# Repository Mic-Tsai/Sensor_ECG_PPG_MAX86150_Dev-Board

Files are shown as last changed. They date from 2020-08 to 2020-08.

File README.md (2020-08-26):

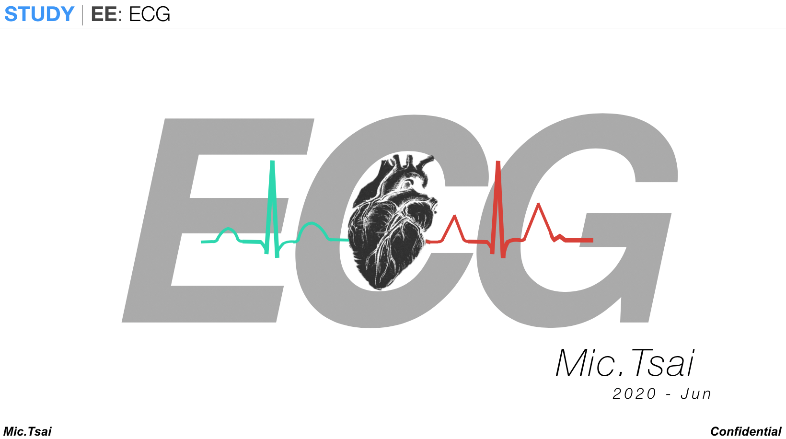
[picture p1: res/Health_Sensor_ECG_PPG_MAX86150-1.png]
*Sensor_MAX86150*

## Sensor_ECG_PPG_MAX86150 | Dev-Board



Arduino based sensor learning project. The feature combines ECG/PPG data with heart rate calculation, plotting the ECG/PPG curve which used Processing on your computer.

 - Bias Cancellation | Store raw data in time, when new data coming that bias level will calculate as hysteresis filter.

 - Heart Rate Detect | Setting upper/lower threshold once your ECG/PPG value cross u/l threshold, check windows will output the BPM results (Both PPG/ECG).

##

### Wireless Support ###

This board also support WiFi transmission via ESPNOW (ESP8266 Broadcast), and need power by battery. And you need 2x esp8266 board.

1) Read receiver esp8266's mac address.
2) Fill it into the transmitter sketch. "ECG_PPG_MAX86150_V5_WiFi_TX"

**A Known Issue**

Sampling rate from MAX86150 set as 200sps, but ESP8266's multiplex with ESP-NOW and sensor hub reading task, it will low down the output sample rate to ~150sps. So, when you measuring your ECG/PPG in real-time plot, it may show the missing R-R interval. (R-peak missing!) Don't worry it just the lower sample rate caused.

```
Arduino tool kit, and require the following material:
- MCU: ESP8266 
- Display: SD1306_128x64_OLED
- Sensor: MAX86150
```
##

For coding example, you need the following library:

* [Adafruit_SSD1306](https://github.com/adafruit/Adafruit_SSD1306)
* [protocentral_max86150_ecg_ppg](https://github.com/Protocentral/protocentral_max86150_ecg_ppg)

## 

Any question or need technical support:

* Contact me via mail (xbcke12345@gmail.com)
* If this project helping. Please generously support =)

   

## 
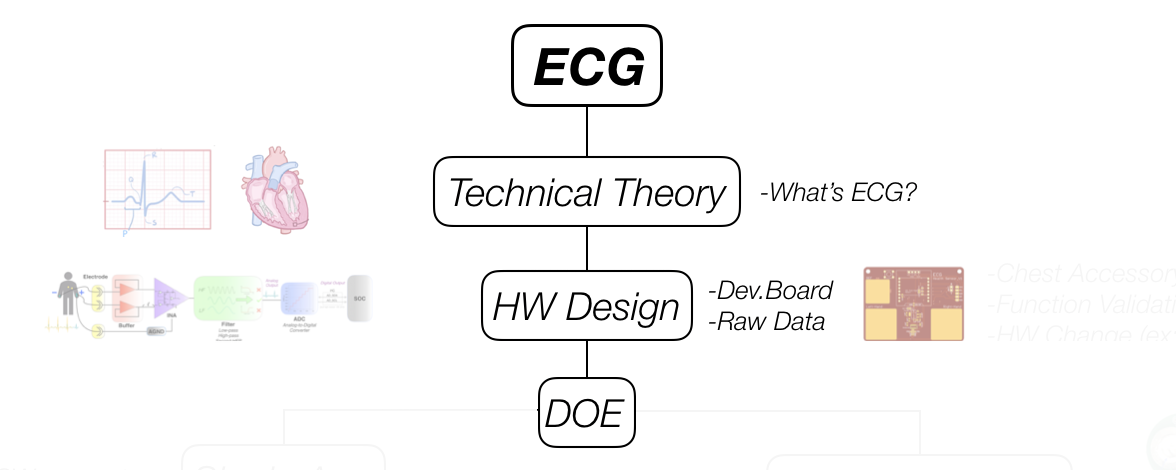
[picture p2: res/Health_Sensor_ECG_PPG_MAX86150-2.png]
*Sensor_MAX86150*

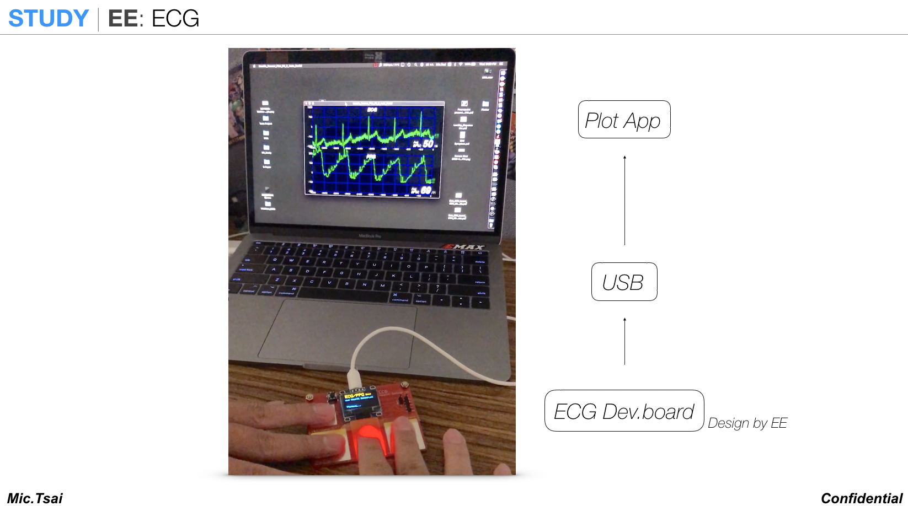
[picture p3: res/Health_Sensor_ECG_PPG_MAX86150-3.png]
*Sensor_MAX86150*

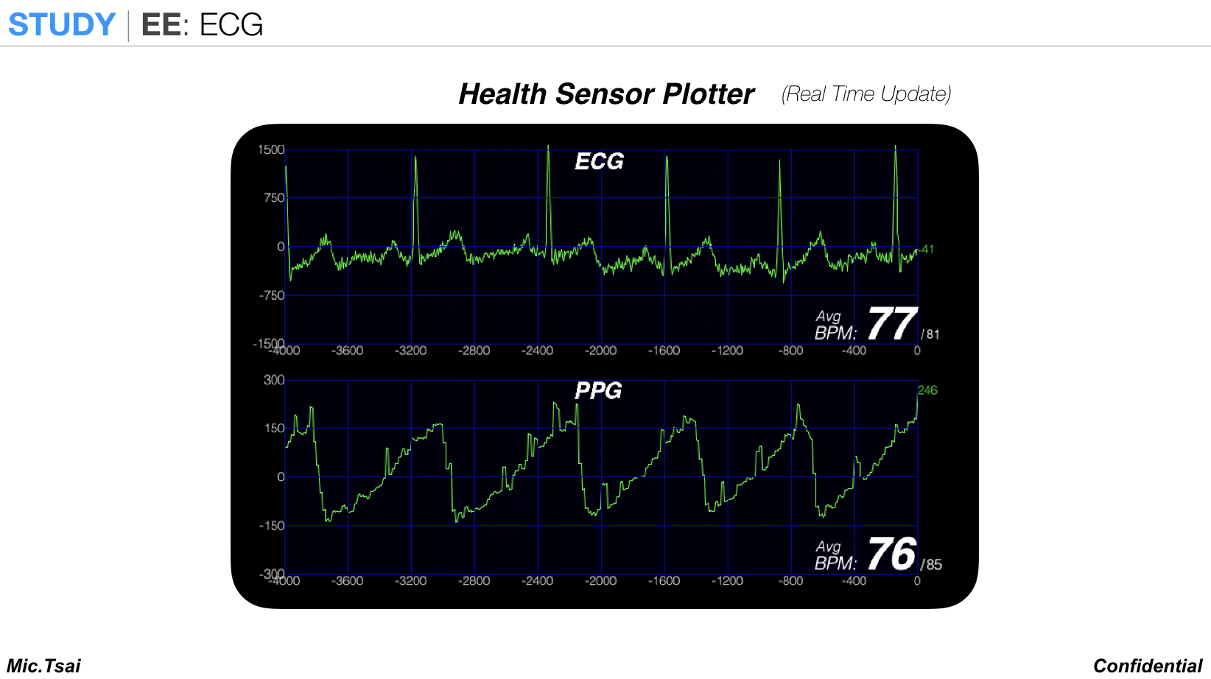
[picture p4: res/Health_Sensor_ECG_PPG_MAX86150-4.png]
*Sensor_MAX86150*

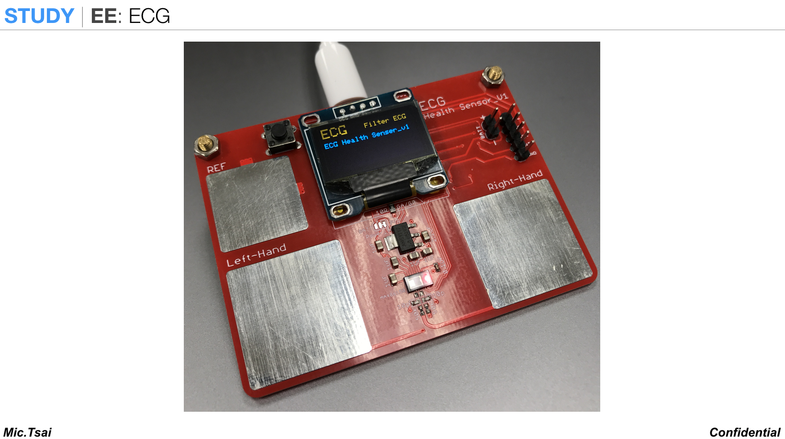
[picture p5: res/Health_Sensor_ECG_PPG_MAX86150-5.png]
*Sensor_MAX86150*

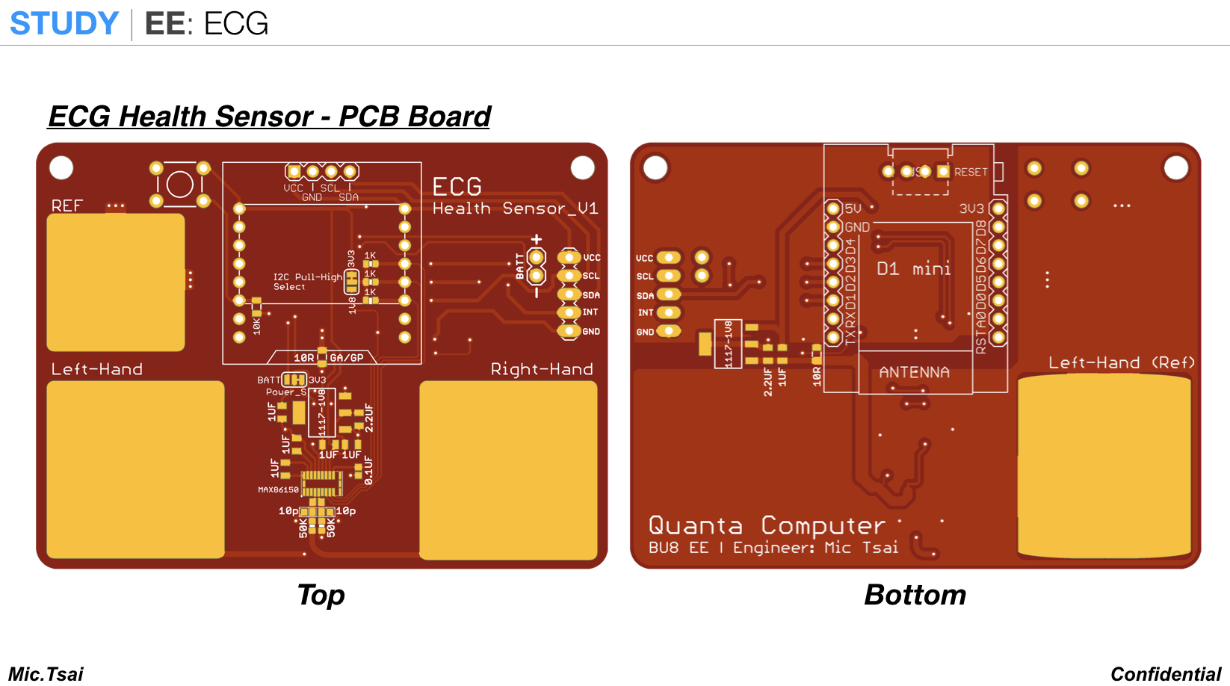
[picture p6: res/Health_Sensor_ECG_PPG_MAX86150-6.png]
*Sensor_MAX86150*

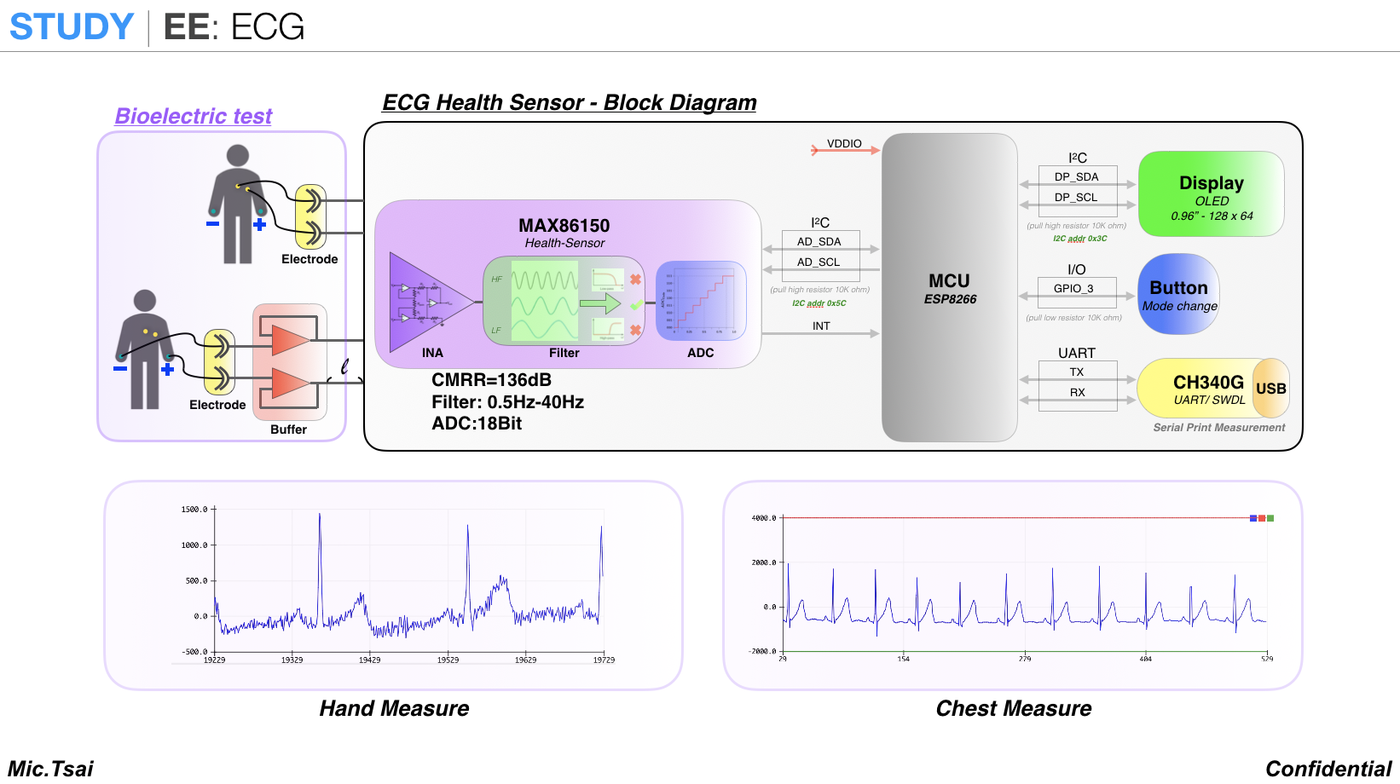
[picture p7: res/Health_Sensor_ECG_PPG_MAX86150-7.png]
*Sensor_MAX86150*

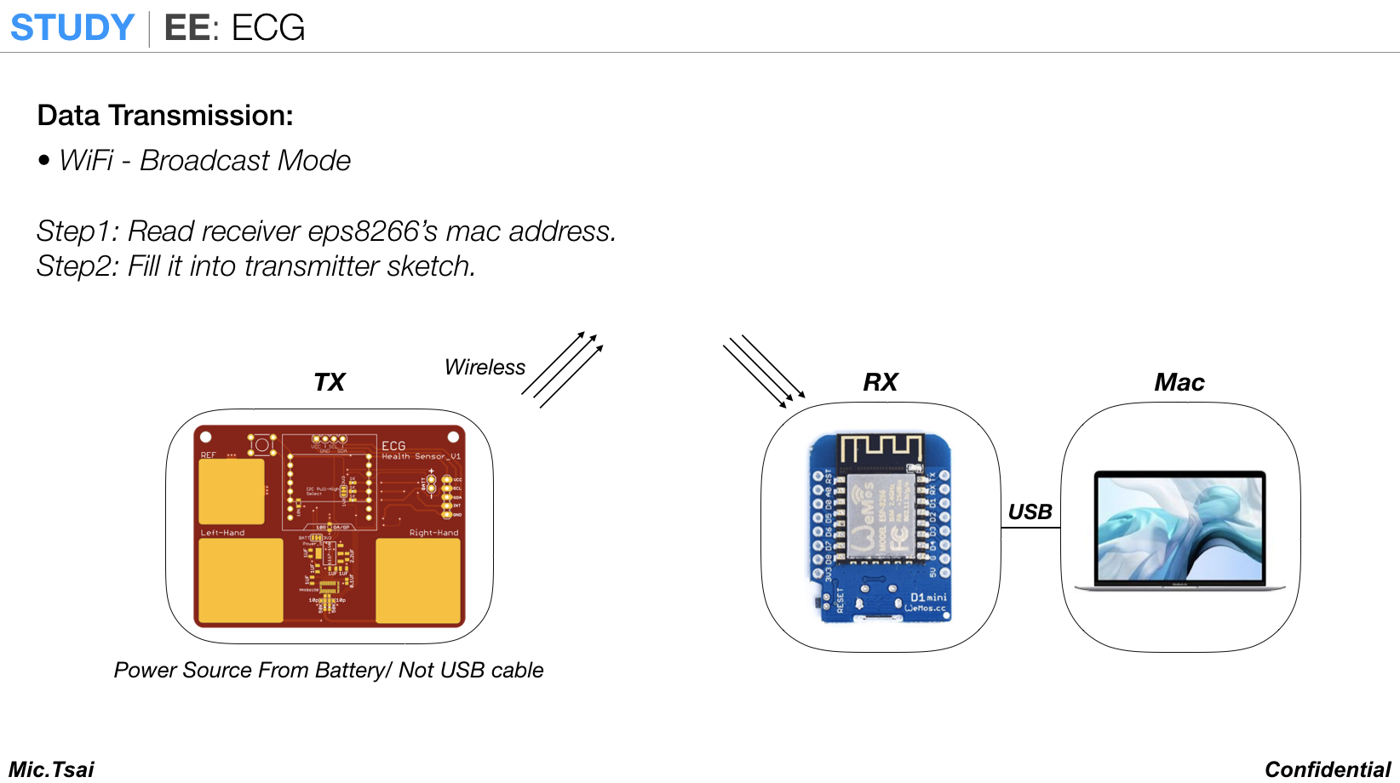
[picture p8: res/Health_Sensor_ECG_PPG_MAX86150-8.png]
*Sensor_MAX86150*

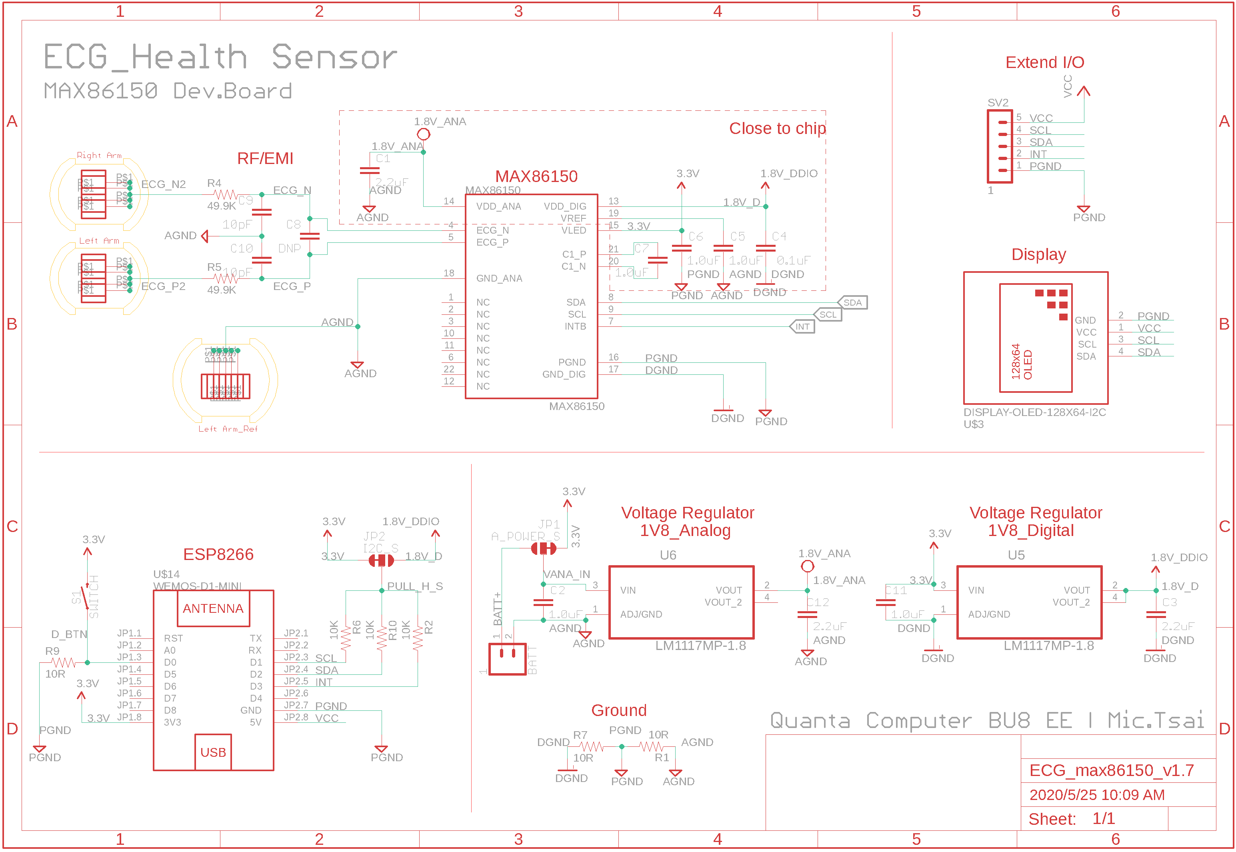
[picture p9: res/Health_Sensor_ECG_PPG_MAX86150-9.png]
*Sensor_MAX86150*

## 

>### License Information
>>This product is open source! Both, our hardware and software are open source and licensed under the following:
>>#### Hardware
>>>All hardware is released under [Creative Commons Share-alike 4.0 International](http://creativecommons.org/licenses/by-sa/4.0/)
>>#### Software 
>>>All software is released under the MIT License [http://opensource.org/licenses/MIT](http://opensource.org/licenses/MIT)
>>#### Documentation
>>>The documentation on this page is released under [Creative Commons Share-alike 4.0 International](http://creativecommons.org/licenses/by-sa/4.0/)

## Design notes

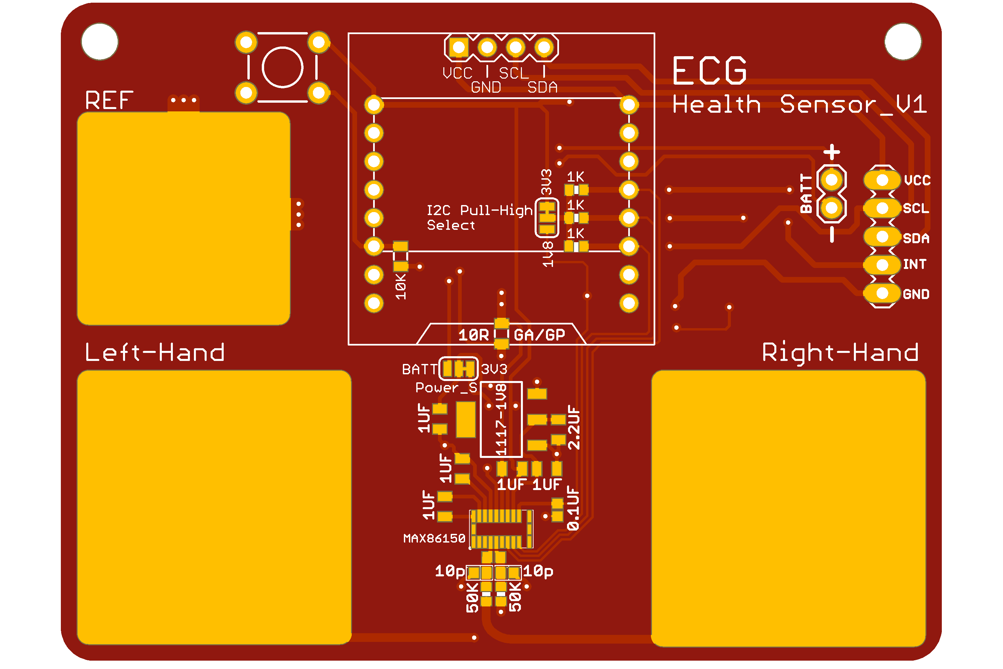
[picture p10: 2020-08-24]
hardware/ECG_max86150_v1.7/ECG_max86150_v1.7_T.png

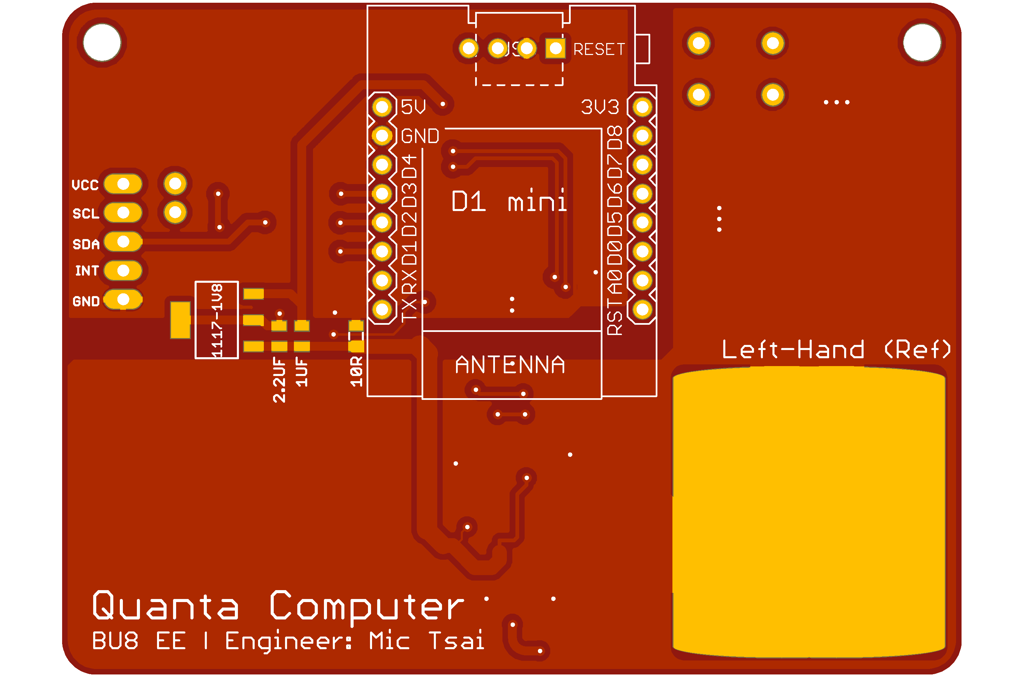
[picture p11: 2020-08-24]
hardware/ECG_max86150_v1.7/ECG_max86150_v1.7_B.png

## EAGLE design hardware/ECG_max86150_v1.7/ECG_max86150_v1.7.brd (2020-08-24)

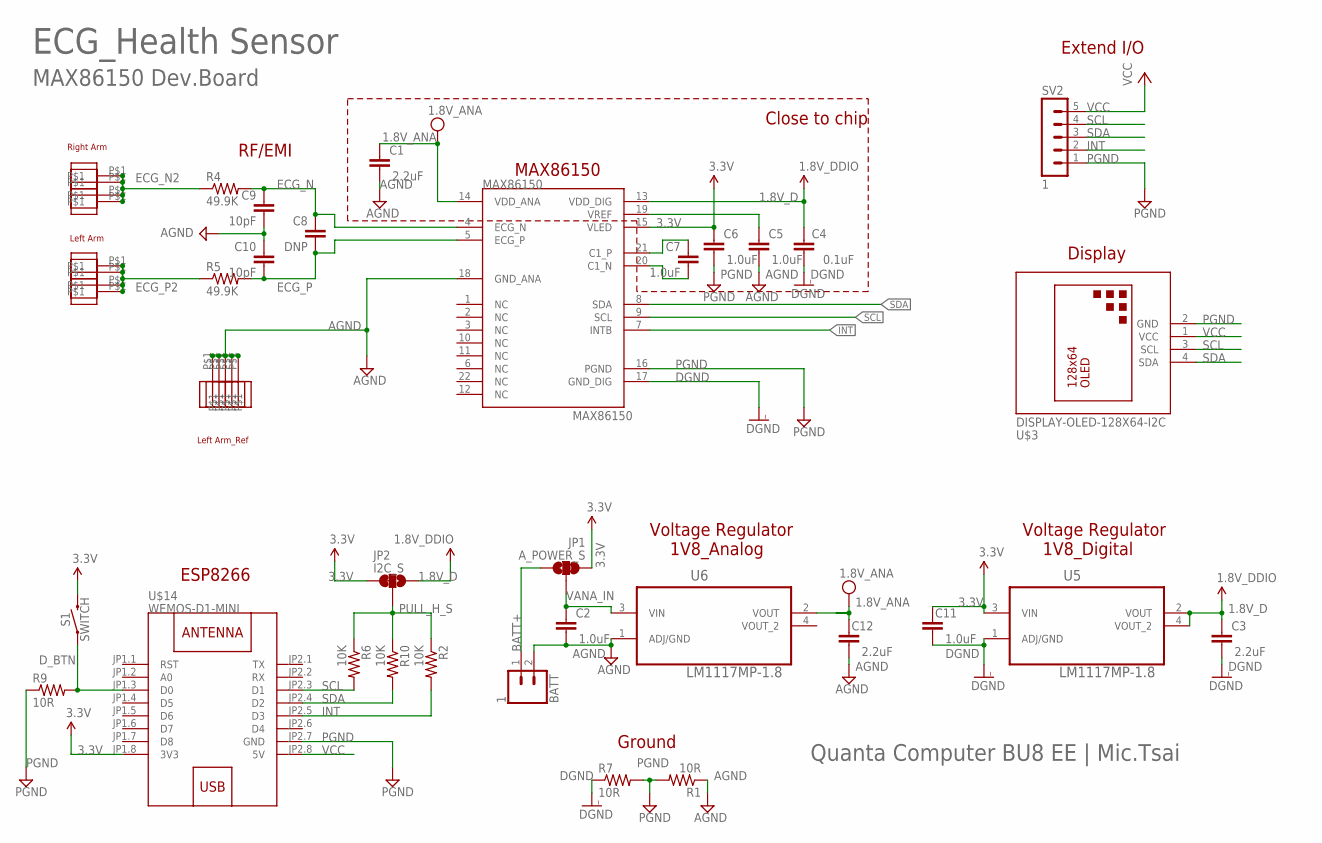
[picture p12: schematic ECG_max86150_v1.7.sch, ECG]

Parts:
BATT: 1; 1X02
C1, C3, C12: 2.2uF; 0805
C2, C5, C6, C7, C11: 1.0uF; 0805
C4: 0.1uF; 0402
C8: DNP; 0402
C9, C10: 10pF; 0402
JP1: A_POWER_S; SMT-JUMPER_3_1-NC_TRACE_SILK
JP2: I2C_S; SMT-JUMPER_3_1-NC_TRACE_SILK
MAX86150: MAX86150
R1, R7, R9: 10R; 0805
R2, R6, R10: 10K; 0402-RES
R4, R5: 49.9K; 0402-RES
S1: SWITCH; TACTILE_SWITCH_PTH_6.0MM
SV2: 1; MA05-1
U5, U6: LM1117MP-1.8; SOT230P696X180-4N
U$1, U$4, U$6, U$7, U$9, U$10, U$11, U$12, U$13, U$15, U$16, U$17, U$18: ECG_PAD; ECG_PAD1
U$3: DISPLAY-OLED-128X64-I2C
U$14: WEMOS-D1-MINI

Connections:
1.8V_ANA: C1.1, C12.1, MAX86150.14 (VDD_ANA), U6.2 (VOUT)
1.8V_D: C3.1, C4.1, JP2.1, MAX86150.13 (VDD_DIG), U5.2 (VOUT), U5.4 (VOUT_2)
3.3V: C6.1, C11.1, JP1.3, JP2.3, MAX86150.15 (VLED), S1.3 (2), U5.3 (VIN), U$14.JP1.8 (3V3)
AGND: BATT.2, C1.2, C2.2, C5.2, C9.2, C10.1, C12.2, MAX86150.18 (GND_ANA), R1.1, U6.1 (ADJ/GND), U$12.P$1, U$13.P$1, U$15.P$1, U$17.P$1, U$18.P$1
BATT+: BATT.1, JP1.1
DGND: C3.2, C4.2, C11.2, MAX86150.17 (GND_DIG), R7.1, U5.1 (ADJ/GND)
D_BTN: R9.2, S1.1, U$14.JP1.3 (D0)
ECG_N: C8.1, C9.1, MAX86150.4 (ECG_N), R4.2
ECG_N2: R4.1, U$9.P$1, U$10.P$1, U$11.P$1, U$16.P$1
ECG_P: C8.2, C10.2, MAX86150.5 (ECG_P), R5.2
ECG_P2: R5.1, U$1.P$1, U$4.P$1, U$6.P$1, U$7.P$1
INT: MAX86150.7 (INTB), R2.2, SV2.2, U$14.JP2.5 (D3)
unnamed: C7.1, MAX86150.21 (C1_P)
unnamed: C7.2, MAX86150.20 (C1_N)
unnamed: C5.1, MAX86150.19 (VREF)
PGND: C6.2, MAX86150.16 (PGND), R1.2, R7.2, R9.1, SV2.1, U$3.2 (GND), U$14.JP2.7 (GND)
PULL_H_S: JP2.2, R2.1, R6.1, R10.1
SCL: MAX86150.9 (SCL), R6.2, SV2.4, U$3.3 (SCL), U$14.JP2.3 (D1)
SDA: MAX86150.8 (SDA), R10.2, SV2.3, U$3.4 (SDA), U$14.JP2.4 (D2)
VANA_IN: C2.1, JP1.2, U6.3 (VIN)
VCC: SV2.5, U$3.1 (VCC), U$14.JP2.8 (5V)

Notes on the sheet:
Close to chip
ECG_Health Sensor
MAX86150 Dev.Board
Quanta Computer BU8 EE | Mic.Tsai
Left Arm
RF/EMI
Ground
Right Arm
Left Arm_Ref
Voltage Regulator 1V8_Analog
Voltage Regulator 1V8_Digital
Extend I/O
MAX86150
ESP8266
Display

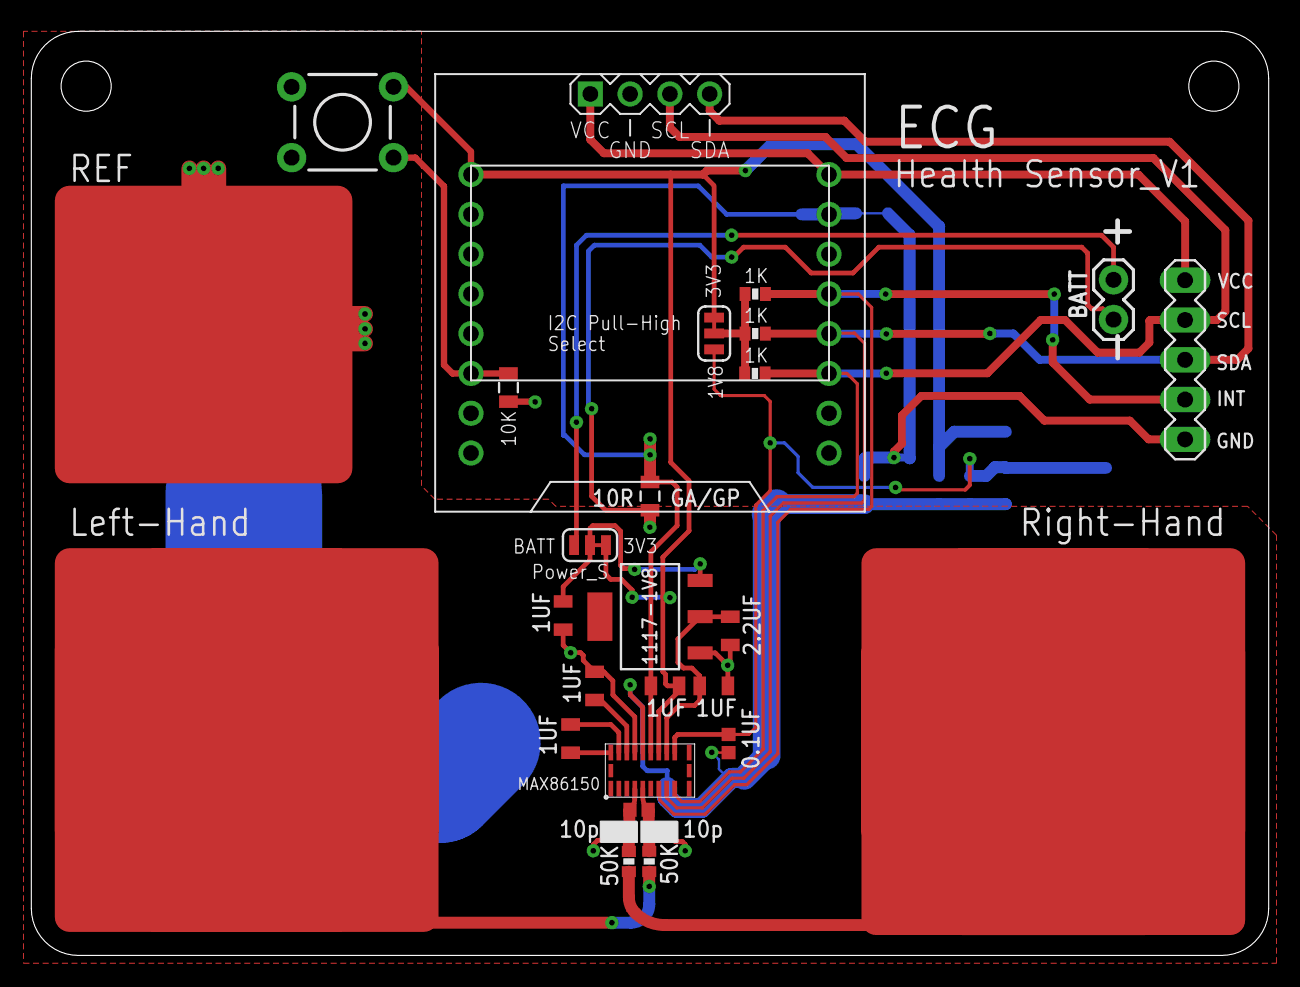
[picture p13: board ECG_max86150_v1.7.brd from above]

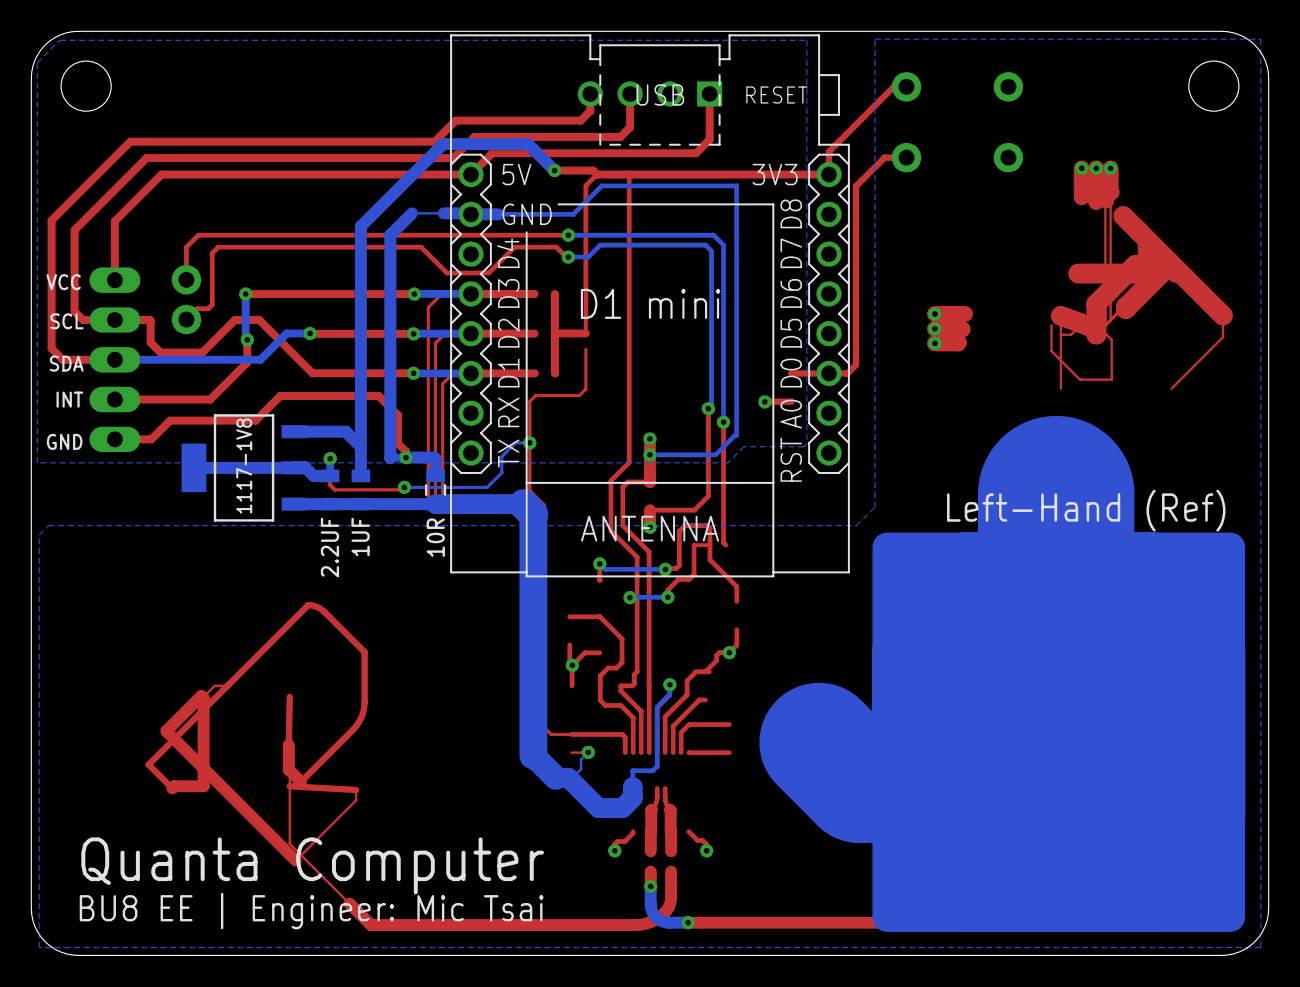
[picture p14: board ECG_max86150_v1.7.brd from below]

Board: 2 copper layers, 79.0 x 59.0 mm, 43 parts (9 on the bottom side), 21 nets.

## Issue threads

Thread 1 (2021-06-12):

Electrode Material, Analog Ground Biasing To Human Body

whathisface, 2021-06-12:
Hello @Mic-Tsai,

Nice work.

I have a question regarding your electrodes - what are they made of?  SST 316?  And, what is the method of attachment?
Are the backs of the electrodes bare metal or is there an insulator on the back?

Your analog ground circuit is interesting - are there any issues with static electricity doing that?

Thanks in advance,
whf

Mic-Tsai, 2021-06-15:
Hi whf,

Electrodes - it’s general pcb copper with HASL (hot air slider leveling). Conductive material will work perfectly (even a clean coin) but, if you consider product reliability…steel wins. Back electrode is the same reference PAD on top (depend on hand measuring position).

Ground - the most interesting issue in bio sensing, prevent your system noise cross-talk to analog level, isolate power/ground…not supply with USB. (AC noise terrible)

Hardware attachment is EAGLE PCB design.

Enjoy😁

Mic

whathisface, 2021-06-15:
Hello Mic,

OK - thanks for the response.
- whf

Closed 2021-06-17.

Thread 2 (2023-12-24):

problem in setup the board

MMWAVEMJK, 2023-12-24:
hello, i have copy your board and made its pcb and i assemble the board but doesn't work. i check all the voltages and all of them is same as pcb design. i have doubt on program and libraries versions.can you send me the library and board manager version ?

Mic-Tsai, 2023-12-24:
I2C level should select 1v8 if you supply the power via arduino mini evk. Please cut the 3v3 trace then short the 1v8 as follows.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

MMWAVEMJK, 2023-12-25:
i do the above but my problem did not resolve. i got below error.
![Uploading k,..JPG…]()

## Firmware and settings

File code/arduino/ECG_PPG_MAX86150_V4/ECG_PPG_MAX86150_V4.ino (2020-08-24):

// ###################################################################################
// # Project: ECG Health Sensor
// # Engineer:  Mic.Tsai
// # Date:  1 June 2020
// # Objective: Dev.board
// # Usage: ESP8266
// # Modified: Mode Select with filter / ECG / PPG
// ###################################################################################

/*
  See the output on the Arduino Plotter utlity by:
  1) Program the code to your Arduino
  2) Place your left hand finger and the right hand finger on the two ECG electrode pads
  3) In the Arduino IDE, Open Tools->'Serial Plotter'
  4) Make sure the drop down is set to 38400 baud
  5) See your ECG and heartbeat
  This code is released under the [MIT License](http://opensource.org/licenses/MIT).

  -VCC = 5V
  -GND = GND
  -SDA = A4 (or SDA)
  -SCL = A5 (or SCL)
  -INT = Not connected
*/

#include <Wire.h>
#include "max86150.h"

// # LCD install
#include <Adafruit_SSD1306.h>
#include <Adafruit_GFX.h>
Adafruit_SSD1306 display(128, 64, &Wire, -1);

byte TestledBrightness = 50; //Options: 0=Off to 255=50mA //0x1F

// # ECG sensor
int16_t ecgsigned16;
int16_t redunsigned16;
uint16_t ppgunsigned16;

MAX86150 max86150Sensor;

int TimerLast=0;
int TimerNow=0;
int Time=0;

int Filter_Value;
int Filter_Value2;
int Value;
int Value2;

// # BTN Mode Select
const int  buttonPin = 16;    // the pin that the pushbutton is attached to

// Variables will change:
int buttonPushCounter = 0;   // counter for the number of button presses
int buttonState = 0;         // current state of the button
int lastButtonState = 0;     // previous state of the button

// PPG
// # Plot 變數宣告區
int a=0;
int lasta=0;
int lastb=0;
int LastTime=0;
int ThisTime;
bool BPMTiming=false;
bool BeatComplete=false;
int BPM=0;

// # 上限下限
#define UpperThreshold 520  
#define LowerThreshold 450

// # Bias
int LevelSea = 0;

// # 平均心跳
const byte RATE_SIZE = 36; //Increase this for more averaging. 18 is good.
byte rates[RATE_SIZE]; //Array of heart rates
byte rateSpot = 0;
long lastBeat = 0; //Time at which the last beat occurred

float beatsPerMinute;
int beatAvg;
int PPGAVG;

void setup()
{
    pinMode(buttonPin, INPUT);
    Serial.begin(38400);
    Serial.println("MAX86150 Basic Readings Example");

    // Initialize sensor
    if (max86150Sensor.begin(Wire, I2C_SPEED_FAST) == false)
    {
        Serial.println("MAX86150 was not found. Please check wiring/power. ");
        while (1);
    }

    //Setup to sense a nice looking saw tooth on the plotter
    byte ledBrightness = 255; //Options: 0=Off to 255=50mA
    byte sampleAverage = 32; //Options: 1, 2, 4, 8, 16, 32
    byte ledMode = 2; //Options: 1 = Red only, 2 = Red + IR, 3 = Red + IR + Green
    int sampleRate = 3200; //Options: 50, 100, 200, 400, 800, 1000, 1600, 3200
    int pulseWidth = 411; //Options: 69, 118, 215, 411
    int adcRange = 16384; //Options: 2048, 4096, 8192, 16384
  
    max86150Sensor.setup(ledBrightness, sampleAverage, ledMode, sampleRate, pulseWidth, adcRange); //Configure sensor with these settings
  

    //Display show...
    // initialize with the I2C addr 0x3C
    Serial.print("Initializing...Display");
    if(!display.begin(SSD1306_SWITCHCAPVCC, 0x3C)) { // Address 0x3D for 128x64
    Serial.println(F("SSD1306 allocation failed"));
    for(;;);
    }
      
    // Clear the buffer.
    display.clearDisplay();
    display.setTextSize(2);
  
      // Display "8WA - ECG"
      display.setTextSize(2); display.setTextColor(WHITE); display.setCursor(0,0); display.println("ECG");
      display.setTextSize(1); display.setCursor(0,20); display.println("ECG Health Senser_v1");
      display.display();
      delay(1000);
  
      // Display "By Mic.Tsai - BU8"
      display.setTextSize(1); display.setTextColor(WHITE); 
      display.setCursor(73,45); display.println("Engineer:");
      display.setCursor(80,55); display.println("Mic.Tsai");
      display.display();
      delay(1000);

      Serial.println("OK!");

      display.clearDisplay();
      display.display();
}

void loop()
{
//>>>>>>>>>>>>>>>>>>>>>>>>>>>>>>>>>>>>>>>>>>>>>>
  // Status change

  buttonState = digitalRead(buttonPin);

  if (buttonState != lastButtonState) {
    if (buttonState == HIGH) {
      buttonPushCounter++;
    }
    delay(100);
  } 
  lastButtonState = buttonState;
//>>>>>>>>>>>>>>>>>>>>>>>>>>>>>>>>>>>>>>>>>>>>>>
  if (buttonPushCounter > 11) {
    buttonPushCounter = 0;
  }
//>>>>>>>>>>>>>>>>>>>>>>>>>>>>>>>>>>>>>>>>>>>>>>


//>>>>>>>>>>>>>>>>>>>>>>>>>>>>>>>>>>>>>>>>>>>>>>
//>>>>>>>>>>>>>>>>>>>>>>>>>>>>>>>>>>>>>>>>>>>>>>


//>>>>>>>>>>>>>>>>>>>>>>>> Mode 0 >>>>>>>>>>>>>>>>>>>>>>>>>>>
//>>>>>>>>>>>>>  Plot Demo = TIME + ECG + PPG >>>>>>>>>>>>>>>
  if (buttonPushCounter == 0) {

      display.clearDisplay();

      // Display "8WA - ECG"
      display.setTextSize(2); display.setTextColor(WHITE); display.setCursor(0,0); display.println("ECG/PPG");
      display.setTextSize(1); display.setCursor(0,20); display.println("ECG Health Senser_v1");
      display.setTextSize(1); display.setTextColor(WHITE); 
      display.setCursor(2,55); display.println("Ploting...");

      // Mode Demo
      display.setTextSize(1); display.setTextColor(WHITE); 
      display.setCursor(90,5); display.println("Demo");
      display.display();
      delay(100); 

      buttonPushCounter++;
  }

  if (buttonPushCounter == 1) {

    ECG();
    Filter_Value = Filter();
    
    ppgunsigned16 = (uint16_t) (max86150Sensor.getFIFORed()>>2);
    Filter_Value2 = Filter2();

    Serial.print(millis());
    Serial.print(",");
    Serial.print(ecgsigned16 - Filter_Value);
    Serial.print(",");
    Serial.print(ppgunsigned16 - Filter_Value2);
    Serial.println(",");
  }

  if (buttonPushCounter == 2) {

      display.clearDisplay();

      // Display "8WA - ECG"
      display.setTextSize(2); display.setTextColor(WHITE); display.setCursor(0,0); display.println("ECG/PPG");
      display.setTextSize(1); display.setCursor(0,20); display.println("ECG Health Senser_v1");
      display.setTextSize(1); display.setTextColor(WHITE); 
      display.setCursor(2,55); display.println("Ploting...");

      // Mode Demo
      display.setTextSize(1); display.setTextColor(WHITE); 
      display.setCursor(90,5); display.println("Demo2");
      display.display();
      delay(100); 

      buttonPushCounter++;
  } 
        
  if (buttonPushCounter == 3) {

    ECG();
    Filter_Value = Filter();
    
    ppgunsigned16 = (uint16_t) (max86150Sensor.getFIFORed()>>2);
    Filter_Value2 = Filter2();

    Serial.print(ecgsigned16 - Filter_Value);
    Serial.print(",");
    Serial.println(ppgunsigned16 - Filter_Value2);
    
 //   Serial.print(ecgsigned16 - Filter_Value);
 //   Serial.print(",");
 //   Serial.println(ppgunsigned16 - Filter_Value2);
  }

  if (buttonPushCounter == 4) {

      display.clearDisplay();

      // Display "8WA - ECG"
      display.setTextSize(2); display.setTextColor(WHITE); display.setCursor(0,0); display.println("ECG");
      display.setTextSize(1); display.setCursor(0,20); display.println("ECG Health Senser_v1");
      display.setTextSize(1); display.setTextColor(WHITE); 
      display.setCursor(2,55); display.println("Ploting...");

      // Mode Demo
      display.setTextSize(1); display.setTextColor(WHITE); 
      display.setCursor(60,5); display.println("Raw ECG");
      display.display();
      delay(100); 

      buttonPushCounter++;
  } 
          
//>>>>>>>>>>>>>>>>>>>>>>>> Mode 2 >>>>>>>>>>>>>>>>>>>>>>>>>>>
//>>>>>>>>>>>>>>>>>>>>>>>  Raw ECG >>>>>>>>>>>>>>>>>>>>>>>>>>

  if (buttonPushCounter == 5) {
    ECG();
    Filter_Value = Filter();
    ppgunsigned16 = (uint16_t) (max86150Sensor.getFIFORed()>>2);
    Serial.print(ecgsigned16);
    Serial.print(",");
    Serial.println(Filter_Value);  
        PlotShow();
  }
  
   if (buttonPushCounter == 6) {

      display.clearDisplay();

      // Display "8WA - ECG"
      display.setTextSize(2); display.setTextColor(WHITE); display.setCursor(0,0); display.println("ECG");
      display.setTextSize(1); display.setCursor(0,20); display.println("ECG Health Senser_v1");
      display.setTextSize(1); display.setTextColor(WHITE); 
      display.setCursor(2,55); display.println("Ploting...");

      // Mode Demo
      display.setTextSize(1); display.setTextColor(WHITE); 
      display.setCursor(60,5); display.println("Filter ECG");
      display.display();
      delay(100); 

      buttonPushCounter++;
   }

//>>>>>>>>>>>>>>>>>>>>>>>> Mode 3 >>>>>>>>>>>>>>>>>>>>>>>>>>>
//>>>>>>>>>>>>>>>>>>>>>  Filter ECG >>>>>>>>>>>>>>>>>>>>>>>>>>

  if (buttonPushCounter == 7) {
    
    ECG();
    ECGFilter();
    PlotShow();
  }
  
  if (buttonPushCounter == 8) {

      display.clearDisplay();

      // Display "8WA - ECG"
      display.setTextSize(2); display.setTextColor(WHITE); display.setCursor(0,0); display.println("PPG");
      display.setTextSize(1); display.setCursor(0,20); display.println("ECG Health Senser_v1");
      display.setTextSize(1); display.setTextColor(WHITE); 
      display.setCursor(2,55); display.println("Ploting...");

      // Mode Demo
      display.setTextSize(1); display.setTextColor(WHITE); 
      display.setCursor(60,5); display.println("Raw PPG");
      display.display();
      delay(100); 

      buttonPushCounter++;
   }

//>>>>>>>>>>>>>>>>>>>>>>>> Mode 4 >>>>>>>>>>>>>>>>>>>>>>>>>>>
//>>>>>>>>>>>>>>>>>>>>>>  Raw PPG >>>>>>>>>>>>>>>>>>>>>>>>>>>

   if (buttonPushCounter == 9) {

    ECG();
    Filter_Value = Filter();
    ppgunsigned16 = (uint16_t) (max86150Sensor.getFIFORed()>>2);
    Filter_Value2 = Filter2(); 
    Serial.print(ppgunsigned16);
    Serial.print(",");
    Serial.println(Filter_Value2); 
    PlotShow();
   }

  if (buttonPushCounter == 10) {

      display.clearDisplay();

      // Display "8WA - PPG"
      display.setTextSize(2); display.setTextColor(WHITE); display.setCursor(0,0); display.println("PPG");
      display.setTextSize(1); display.setCursor(0,20); display.println("ECG Health Senser_v1");
      display.setTextSize(1); display.setTextColor(WHITE); 
      display.setCursor(2,55); display.println("Ploting...");

      // Mode Demo
      display.setTextSize(1); display.setTextColor(WHITE); 
      display.setCursor(60,5); display.println("Filter PPG");
      display.display();
      delay(100); 

      buttonPushCounter++;
  }

//>>>>>>>>>>>>>>>>>>>>>>>> Mode 3 >>>>>>>>>>>>>>>>>>>>>>>>>>>
//>>>>>>>>>>>>>>>>>>>>>  Filter PPG >>>>>>>>>>>>>>>>>>>>>>>>>>

  if (buttonPushCounter == 11) {

    ECG();
    Filter_Value = Filter();
    ppgunsigned16 = (uint16_t) (max86150Sensor.getFIFORed()>>2);
    Filter_Value2 = Filter2();
    Serial.println(ppgunsigned16 - Filter_Value2);
    PlotShow();
  }

}
//>>>>>>>>>>>>>>>>>>>>>>>>>>>>>>>>>>>>>>>>>>>>>>
//>>>>>>>>>>>>>>>>>>>>>>>>>>>>>>>>>>>>>>>>>>>>>>

//>>>>>>>>>>>>>>>>>>>>>>>>>>>>>>>>>>>>>>>>>>>>>>>>>>>>>>>>>>>>>>>>>>>>>>
//>>>>>>>>>>>>>>>>>>>>>>>>>>> Get ECG Data >>>>>>>>>>>>>>>>>>>>>>>>>>>>>
//>>>>>>>>>>>>>>>>>>>>>>>>>>>>>>>>>>>>>>>>>>>>>>>>>>>>>>>>>>>>>>>>>>>>>>
void ECG()
{ 
      ecgsigned16 = (int16_t) (max86150Sensor.getECG()>>2);
}
//>>>>>>>>>>>>>>>>>>>>>>>>>>>>>>>>>>>>>>>>>>>>>>>>>>>>>>>>>>>>>>>>>>>>>>
//>>>>>>>>>>>>>>>>>>>>>>>>>>> Get ECG Data >>>>>>>>>>>>>>>>>>>>>>>>>>>>>
//>>>>>>>>>>>>>>>>>>>>>>>>>>>>>>>>>>>>>>>>>>>>>>>>>>>>>>>>>>>>>>>>>>>>>>


//>>>>>>>>>>>>>>>>>>>>>>>>>>>>>>>>>>>>>>>>>>>>>>>>>>>>>>>>>>>>>>>>>>>>>>
//>>>>>>>>>>>>>>>>>>>>>>>>>>> Get PPG Data >>>>>>>>>>>>>>>>>>>>>>>>>>>>>
//>>>>>>>>>>>>>>>>>>>>>>>>>>>>>>>>>>>>>>>>>>>>>>>>>>>>>>>>>>>>>>>>>>>>>>
void PPG()
{ 
     ppgunsigned16 = (uint16_t) (max86150Sensor.getFIFORed()>>2);
}
//>>>>>>>>>>>>>>>>>>>>>>>>>>>>>>>>>>>>>>>>>>>>>>>>>>>>>>>>>>>>>>>>>>>>>>
//>>>>>>>>>>>>>>>>>>>>>>>>>>> Get PPG Data >>>>>>>>>>>>>>>>>>>>>>>>>>>>>
//>>>>>>>>>>>>>>>>>>>>>>>>>>>>>>>>>>>>>>>>>>>>>>>>>>>>>>>>>>>>>>>>>>>>>>
void ECGFilter()
{ 
    Filter_Value = Filter();
    Serial.println(ecgsigned16 - Filter_Value); 
}
//>>>>>>>>>>>>>>>>>>>>>>>>>>>>>>>>>>>>>>>>>>>>>>>>>>>>>>>>>>>>>>>>>>>>>>
//>>>>>>>>>>>>>>>>>>>>>> Plot Timer Check  >>>>>>>>>>>>>>>>>>>>>>>>>>>>>
//>>>>>>>>>>>>>>>>>>>>>>>>>>>>>>>>>>>>>>>>>>>>>>>>>>>>>>>>>>>>>>>>>>>>>>
void PlotShow()
{
    TimerNow = millis();
    Time = TimerNow - TimerLast;
    
    if (Time < 42)
    {
      display.writeFillRect(0,53,60,20,BLACK);
      
          if (buttonPushCounter == 0) {
          display.writeFillRect(0,40,60,10,BLACK);
          }
          
      display.display();
    } 
    if (Time < 5000 && Time > 4950)
    {
      display.writeFillRect(0,53,60,20,WHITE);
      display.setTextSize(1); display.setTextColor(BLACK); 
      display.setCursor(2,55); display.println("Ploting...");
      
          if (buttonPushCounter == 0) {
          display.writeFillRect(0,40,40,10,WHITE);
          display.setTextSize(1); display.setTextColor(BLACK); 
          display.setCursor(2,42); display.println("Filter");
          }

      
      display.display();
    }    
    if (Time > 10000)
    {
      display.writeFillRect(0,53,60,20,BLACK);

          if (buttonPushCounter == 0) {
          display.writeFillRect(0,40,60,10,BLACK);
          }
      
      display.display();
      TimerLast = TimerNow;
    }
    //  Serial.print("   , "); 
    //  Serial.println(Time); 
}   
//>>>>>>>>>>>>>>>>>>>>>>>>>>>>>>>>>>>>>>>>>>>>>>>>>>>>>>>>>>>>>>>>>>>>>>
//>>>>>>>>>>>>>>>>>>>>>> Plot Timer Check  >>>>>>>>>>>>>>>>>>>>>>>>>>>>>
//>>>>>>>>>>>>>>>>>>>>>>>>>>>>>>>>>>>>>>>>>>>>>>>>>>>>>>>>>>>>>>>>>>>>>>


// ecg data in
int Get_AD() {
  return ecgsigned16;
}

// 一階滯後濾波法
#define FILTER_A 0.01
int Filter() {
  int NewValue;
  NewValue = Get_AD();
  Value = (int)((float)NewValue * FILTER_A + (1.0 - FILTER_A) * (float)Value);
  return Value;
}

//>>>>>>>>>>>>>>>>>>>>>>>>>>>> PPG  >>>>>>>>>>>>>>>>>>>>>>>>>>>>>>>>>>>>

// ecg data in
int Get_AD2() {
  return ppgunsigned16;
}

// 一階滯後濾波法
#define FILTER_A2 0.01
int Filter2() {
  int NewValue2;
  NewValue2 = Get_AD2();
  Value2 = (int)((float)NewValue2 * FILTER_A2 + (1.0 - FILTER_A2) * (float)Value2);
  return Value2;
}

//>>>>>>>>>>>>>>>>>>>>>>>>>>>>>>>>>>>>>>>>>>>>>>>>>>>>>>>>>>>>>>>>>>>>>>
//>>>>>>>>>>>>>>>>>>>>>>>>>>>>>>>>>>>>>>>>>>>>>>>>>>>>>>>>>>>>>>>>>>>>>>

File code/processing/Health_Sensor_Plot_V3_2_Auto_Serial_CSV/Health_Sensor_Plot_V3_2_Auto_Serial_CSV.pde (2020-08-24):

// Base on ArduinoScope 
// ###################################################################################
// # Project: ECG Health Sensor Plots
// # Engineer:  Mic.Tsai
// # Date:  10 June 2020
// # Objective: Dev.board
// # Usage: ESP8266
// # Modified: Mode Select with filter and PPG
// ###################################################################################

import java.io.BufferedWriter;
import java.io.FileWriter;
String outFilename = "/Users/mic/Desktop/ECG+PPG_Data.csv";


import processing.serial.*;
Serial ArduinoPort;  // Create object from Serial class
 
int NumOfScopes,NumOfInput=2;
int data_span=10000;
Strage dfs = new Strage();
Scope[] sp;
 
int fontsize=16;
PFont myFont;
PFont myFont2;
PFont myFont3;
 
//============================= # ECG BPM calculate 
int LastTimeECG=0;
int ThisTimeECG; 
float inByteECG = 0;
int BPMECG = 0;
int beat_oldECG = 0;
float[] beatsECG = new float[500];  // Used to calculate average BPM
int averagebuffervalueecg=5;
int beatIndexECG;
boolean belowThresholdECG = true; 

int valssECG;
int timestampAllECG;
 
boolean BPMTimingECG=false;
boolean BeatCompleteECG=false;

float beatsPerMinuteECG;
int beatAvgECG;
int averageECG = 0;
 
//============================= # ECG BPM calculate 

//============================= # PPG BPM calculate 
int LastTime=0;
int ThisTime; 
float inByte = 0;
int BPM = 0;
int beat_old = 0;
float[] beats = new float[500];  // Used to calculate average BPM
int averagebuffervalueppg=5;
int beatIndex;
boolean belowThreshold = true; 

int valssPPG;
int timestampAll;
 
boolean BPMTiming=false;
boolean BeatComplete=false;

float beatsPerMinute;
int beatAvg;
int averageppg = 0;

//============================= # PPG BPM calculate 

//>>>>>>>>>>>>>>>>>>>>>>>>>>>>>>>>>>>>>>>>>>>>>>>>>>>>>>>>>>>>>>>>>>>>>>>>>>>>>>>>>>Set ECG Limit>>>>>>>
// # ECG limit
float UpperThresholdECG = 750  ;
float LowerThresholdECG = 0  ;
//>>>>>>>>>>>>>>>>>>>>>>>>>>>>>>>>>>>>>>>>>>>>>>>>>>>>>>>>>>>>>>>>>>>>>>>>>>>>>>>>>>Set ECG Limit>>>>>>>

//>>>>>>>>>>>>>>>>>>>>>>>>>>>>>>>>>>>>>>>>>>>>>>>>>>>>>>>>>>>>>>>>>>>>>>>>>>>>>>>>>>Set PPG Limit>>>>>>>
// # PPG limit
float UpperThreshold = 100  ;
float LowerThreshold = 0  ;
//>>>>>>>>>>>>>>>>>>>>>>>>>>>>>>>>>>>>>>>>>>>>>>>>>>>>>>>>>>>>>>>>>>>>>>>>>>>>>>>>>>Set PPG Limit>>>>>>>

void setup() 
{
 //>>>>>>>>>>>>>>>>>>>>>>>>>>>>>>>>>>>>>>>>>>>>>>>>>>>>>>>>>>>>>>>>>>>>>>>>>>>>>>>>>>Set COM PORT Here>>>>>>>
  boolean portNr = activateSerialPort("tty.usbserial", 38400);  // Search Phrase and speed
  ArduinoPort.bufferUntil(10);
 //>>>>>>>>>>>>>>>>>>>>>>>>>>>>>>>>>>>>>>>>>>>>>>>>>>>>>>>>>>>>>>>>>>>>>>>>>>>>>>>>>>Set COM PORT Here>>>>>>>

 //>>>>>>>>>>>>>>>>>>>>>>>>>>>>>>>>>>>>>>>>>>>>>>>>>>>>>>>>>>>>>>>>>>>>>>>>>>>>>>>>>>Set Screen Here>>>>>>>
  // Screen
  size(800, 500);
  //size(700, 500);
 //>>>>>>>>>>>>>>>>>>>>>>>>>>>>>>>>>>>>>>>>>>>>>>>>>>>>>>>>>>>>>>>>>>>>>>>>>>>>>>>>>>Set Screen Here>>>>>>>

  NumOfScopes=2;
  sp = new Scope[NumOfScopes];
  sp[0]= new Scope(0,50,10,width-100,height/2-35,1500,-1500,1000,10);
  sp[1]= new Scope(1,50,height/2+15,width-100,height/2-35,300,-300,1000,10);
 
  myFont = loadFont("Helvetica-Light-15.vlw");
  myFont2 = loadFont("Helvetica-LightOblique-20.vlw");
  myFont3 = loadFont("Helvetica-BoldOblique-72.vlw");
  textFont(myFont,fontsize);  
}



boolean activateSerialPort(String partOfPortName, int SerialSpeed) {
  boolean portIsActivated = false;
  int portIndex = -1;
  
  for(int i = 0; i < Serial.list().length; i++) {   // go thru all serial ports
    print(i);    
    
    if(Serial.list()[i].indexOf(partOfPortName) > 0) { // chech if name match
      portIndex = i;
      print("*");
    }
    println("\t" + Serial.list()[i]);
  }
  
  if(portIndex < 0 ) {
    println("Error: No serial port found - " + partOfPortName);
  }else{
    ArduinoPort = new Serial(this, Serial.list()[portIndex], SerialSpeed);
    println("Serial conection: " + Serial.list()[portIndex] + " speed: " + SerialSpeed);  // activate
  }
  return portIsActivated;  
}
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

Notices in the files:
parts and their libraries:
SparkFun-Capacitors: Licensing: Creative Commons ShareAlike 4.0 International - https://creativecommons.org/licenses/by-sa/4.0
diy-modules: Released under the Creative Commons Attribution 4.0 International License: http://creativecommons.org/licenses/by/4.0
